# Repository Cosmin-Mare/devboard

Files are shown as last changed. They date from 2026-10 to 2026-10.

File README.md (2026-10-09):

# RP2040 Dev Board

A small, Pico-style development board built around the **RP2040**, designed in **KiCad 10**. USB-C, 3.3 V LDO, 2 MB QSPI flash, a BOOTSEL button, SWD header, and every GPIO broken out to two 20-pin 2.54 mm headers. Made to be ordered fully assembled from JLCPCB.

Screenshot 2026-10-06 at 7 39 09 PM
Screenshot 2026-10-06 at 7 42 24 PM

| | |
|---|---|
| MCU | Raspberry Pi RP2040 (QFN-56), 12 MHz crystal |
| Flash | Winbond W25Q16JV, 16 Mbit (2 MB) QSPI |
| Power | USB-C (5 V) → MCP1700-3.3 LDO (250 mA) |
| I/O | 26 GPIO (incl. 4 ADC), RUN, VBUS, 3V3, GND on headers; 3-pin SWD (1.27 mm) |
| Controls | BOOTSEL button (no reset button – RUN is on a header pin) |
| Board | 21 × 51 mm, 2-layer, 1.6 mm, headers 17.78 mm (700 mil) apart |
| Assembly | All SMD on the top side (JLCPCB), pin headers hand-soldered |

## Repository layout

```
hardware/kicad/        KiCad 10 project (schematic + PCB) – the source of truth
fabrication/gerbers/   Gerbers, drill files, .gbrjob exported from KiCad
fabrication/jlcpcb/    Ready-to-upload files: gerbers zip, bom.csv, cpl.csv
fabrication/extras/    IPC-D-356 netlist, ODB++, IPC-2581 XML, KiCad board report (.rpt)
bom/bom.csv            Full BOM with MPN + LCSC numbers
bom/BOM.md             Readable BOM
bom/jlcpcb-bom-match-*.xlsx   JLCPCB's BOM-tool match result (stock/prices at the time)
docs/ORDERING.md       Step-by-step JLCPCB order
docs/ASSEMBLY.md       What JLCPCB places vs. what you solder, plus hand-assembly notes
docs/BRINGUP.md       First power-up, flashing, and test checklist
docs/PINOUT.md         Header pinout
```

## Quick start

1. **Order** – follow [docs/ORDERING.md](docs/ORDERING.md). Upload `fabrication/jlcpcb/devboard-gerbers.zip`, then `bom.csv` and `cpl.csv`.
2. **Solder** the two 20-pin headers (and optionally the SWD header) – see [docs/ASSEMBLY.md](docs/ASSEMBLY.md).
3. **Bring up** – hold BOOTSEL, plug in USB-C, copy a `.uf2` onto the `RPI-RP2` drive. See [docs/BRINGUP.md](docs/BRINGUP.md).

## Editing the design

Open `hardware/kicad/devboard.kicad_pro` in KiCad 10. After changes, re-export Gerbers/drill (`File → Fabrication Outputs`), and the position file (`Fabrication Outputs → Component Placement`, CSV, SMD only, millimetres), then refresh `fabrication/` and `bom/`.

## Known notes / things to check before a re-order

- The schematic value for U3 reads `W25Q16JVZPIQ TR`, but JLCPCB matched `W25Q16JVUXIQ` (LCSC C2843335), which is the USON-8 3×2 mm variant matching the footprint. Consider correcting the schematic value so the BOM and part agree.
- JLCPCB's BOM tool flagged several passives as "comment does not match" (value text differs from the part description). The matches are the intended values; review once in the order preview.
- Always check part rotations in JLCPCB's 3D/placement preview (USB-C, RP2040 pin-1, regulator, crystal) before paying – CPL rotation conventions differ between KiCad and JLCPCB.
- No power LED, user LED or reset button are fitted.

## License

MIT. See [LICENSE](LICENSE).

---

Designed by [Cosmin Mare](https://mare-cosmin.ro/en/).

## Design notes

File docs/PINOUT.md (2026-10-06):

# Pinout

Two 20-pin 2.54 mm headers, 17.78 mm apart (same as a Raspberry Pi Pico). **Pin 1 is the end nearest the USB-C connector.** This is *not* the Pico pin order – pins are in the order below.

| Pin | J2 (left) | J3 (right) |
|---:|---|---|
| 1 | GPIO0 | VBUS (5 V from USB) |
| 2 | GPIO1 | GPIO29 / ADC3 |
| 3 | GND | GND |
| 4 | GPIO2 | GPIO28 / ADC2 |
| 5 | GPIO3 | +3V3 (regulator output) |
| 6 | GPIO4 | GPIO27 / ADC1 |
| 7 | GPIO5 | GPIO26 / ADC0 |
| 8 | GND | GND |
| 9 | GPIO6 | GPIO24 |
| 10 | GPIO7 | GPIO23 |
| 11 | GPIO8 | RUN (pull low to reset) |
| 12 | GPIO9 | GPIO22 |
| 13 | GND | GND |
| 14 | GPIO10 | GPIO21 |
| 15 | GPIO11 | GPIO20 |
| 16 | GPIO12 | GPIO19 |
| 17 | GPIO13 | GPIO18 |
| 18 | GND | GND |
| 19 | GPIO14 | GPIO17 |
| 20 | GPIO15 | GPIO16 |

**J4 – SWD (1.27 mm, 3-pin):** 1 = SWCLK, 2 = GND, 3 = SWDIO.

Notes
- GPIO29/ADC3 also senses VSYS on a Pico; here it is a free pin.
- GPIO24 and GPIO23 are exposed; GPIO25 (Pico's LED) is not.
- The 3V3 rail is from a 250 mA LDO shared with the RP2040 – budget accordingly.

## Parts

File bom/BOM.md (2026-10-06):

# Bill of Materials

Per board. 33 parts total (16 line items). Full data incl. manufacturer/MPN in [bom.csv](bom.csv).

| Designators | Qty | Value | Footprint | MPN | LCSC | Assembled by JLCPCB |
|---|--:|---|---|---|---|---|
| C1,C10 | 2 | 1uF | C_0402_1005Metric | CL05A105KA5NQNC | [C52923](https://www.lcsc.com/product-detail/C52923.html) | Yes |
| C2,C3,C4,C5,C6,C7,C8,C9,C11,C12,C17 | 11 | 0.1uF | C_0402_1005Metric | CL05B104KO5NNNC | [C1525](https://www.lcsc.com/product-detail/C1525.html) | Yes |
| C13,C14 | 2 | 10uF | C_0603_1608Metric | CL10A106KP8NNNC | [C19702](https://www.lcsc.com/product-detail/C19702.html) | Yes |
| C15,C16 | 2 | 33pF | C_0402_1005Metric | 0402CG330J500NT | [C1562](https://www.lcsc.com/product-detail/C1562.html) | Yes |
| J1 | 1 | USB_C_Receptacle_USB2.0_14P | USB_C_Receptacle_HRO_TYPE-C-31-M-12 | TYPE-C-31-M-12 | [C165948](https://www.lcsc.com/product-detail/C165948.html) | Yes |
| J2,J3 | 2 | Conn_01x20 | PinHeader_1x20_P2.54mm_Vertical | 2.54-1*20P直针 | [C50981](https://www.lcsc.com/product-detail/C50981.html) | No (hand-solder) |
| J4 | 1 | Conn_01x03 | PinHeader_1x03_P2.54mm_Vertical | 1.27-1*3P针 | [C24980](https://www.lcsc.com/product-detail/C24980.html) | No (hand-solder) |
| R1,R2 | 2 | 5.1k | R_0402_1005Metric | 0402WGF5101TCE | [C25905](https://www.lcsc.com/product-detail/C25905.html) | Yes |
| R3,R4 | 2 | 27 | R_0402_1005Metric | 0402WGF270JTCE | [C25100](https://www.lcsc.com/product-detail/C25100.html) | Yes |
| R5,R7 | 2 | 1k | R_0402_1005Metric | 0402WGF1001TCE | [C11702](https://www.lcsc.com/product-detail/C11702.html) | Yes |
| R6 | 1 | 10k | R_0402_1005Metric | 0402WGF1002TCE | [C25744](https://www.lcsc.com/product-detail/C25744.html) | Yes |
| SW1 | 1 | SW_Push | SW_Push_SPST_NO_Alps_SKRK | TS-1088-AR02016 | [C720477](https://www.lcsc.com/product-detail/C720477.html) | Yes |
| U1 | 1 | RP2040 | QFN-56-1EP_7x7mm_P0.4mm_EP3.2x3.2mm | RP2040 | [C2040](https://www.lcsc.com/product-detail/C2040.html) | Yes |
| U2 | 1 | MCP1700x-330xxTT | SOT-23 | MCP1700T-3302E/TT | [C39051](https://www.lcsc.com/product-detail/C39051.html) | Yes |
| U3 | 1 | W25Q16JVZPIQTR | Winbond_USON-8-1EP_3x2mm_P0.5mm_EP0.2x1.6mm | W25Q16JVUXIQ | [C2843335](https://www.lcsc.com/product-detail/C2843335.html) | Yes |
| Y1 | 1 | 12MHz | Crystal_SMD_3225-4Pin_3.2x2.5mm | X322512MSB4SI | [C9002](https://www.lcsc.com/product-detail/C9002.html) | Yes |

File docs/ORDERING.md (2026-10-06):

# Ordering from JLCPCB (PCB + assembly)

Files are in `fabrication/jlcpcb/`.

1. Go to <https://jlcpcb.com> → **Order now** → upload `devboard-gerbers.zip`.
2. Board settings that match the design:
   - Layers: **2**, Dimensions: **21.05 × 51.05 mm**
   - Thickness: **1.6 mm**, Surface finish: HASL (lead-free) or ENIG (your choice – the design has no special requirement)
   - Min track/space 0.2 mm, min drill 0.3 mm (standard capability)
3. Enable **PCB Assembly** → **Assemble top side only**. Pick quantity (the saved match was for 5 boards).
4. Upload `bom.csv` and `cpl.csv`. Make sure every row matches the LCSC number in the table below.
5. In the placement preview, check **pin-1 and rotation** of: U1 (RP2040), U2 (MCP1700 SOT-23), U3 (flash), Y1 (crystal), J1 (USB-C), SW1. Fix rotation in the preview if anything looks wrong.
6. J2, J3 (20-pin headers) and J4 (3-pin SWD header) showed **quantity 0** in the saved JLCPCB match – they are through-hole parts you solder yourself (see [ASSEMBLY.md](ASSEMBLY.md)).
7. Review the price and place the order.

## LCSC parts

| Ref | Value | LCSC | Type |
|---|---|---|---|
| C1, C10 | 1 µF 0402 | C52923 | Basic |
| C2–C9, C11, C12, C17 | 100 nF 0402 | C1525 | Basic |
| C13, C14 | 10 µF 0603 | C19702 | Basic |
| C15, C16 | 33 pF 0402 | C1562 | Basic |
| J1 | USB-C (HRO TYPE-C-31-M-12) | C165948 | Extended |
| R1, R2 | 5.1 kΩ 0402 | C25905 | Basic |
| R3, R4 | 27 Ω 0402 | C25100 | Extended |
| R5, R7 | 1 kΩ 0402 | C11702 | Basic |
| R6 | 10 kΩ 0402 | C25744 | Basic |
| SW1 | Tactile 4×3 mm (XUNPU TS-1088-AR02016) | C720477 | Basic |
| U1 | RP2040 | C2040 | Extended |
| U2 | MCP1700T-3302E/TT | C39051 | Extended |
| U3 | W25Q16JVUXIQ | C2843335 | Extended |
| Y1 | 12 MHz 3225 crystal (YXC X322512MSB4SI) | C9002 | Basic |
| J2, J3 *(hand-solder)* | 1×20 pin header 2.54 mm | C50981 | Extended |
| J4 *(hand-solder)* | 1×3 pin header 1.27 mm | C24980 | Extended |

The last saved JLCPCB estimate (2026-10-06, 5 assembled boards) was **~$17.27** for assembly parts; stock and prices change, so re-match before ordering. Extended parts add a per-part loading fee.

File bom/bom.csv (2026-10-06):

Designators | Qty | Value | Footprint | Manufacturer | MPN | LCSC | JLCPCB lib | Assembled by JLCPCB
C1,C10 | 2 | 1uF | C_0402_1005Metric | Samsung Electro-Mechanics | CL05A105KA5NQNC | C52923 | Basic | Yes
C2,C3,C4,C5,C6,C7,C8,C9,C11,C12,C17 | 11 | 0.1uF | C_0402_1005Metric | Samsung Electro-Mechanics | CL05B104KO5NNNC | C1525 | Basic | Yes
C13,C14 | 2 | 10uF | C_0603_1608Metric | Samsung Electro-Mechanics | CL10A106KP8NNNC | C19702 | Basic | Yes
C15,C16 | 2 | 33pF | C_0402_1005Metric | FH (Guangdong Fenghua Advanced Tech) | 0402CG330J500NT | C1562 | Basic | Yes
J1 | 1 | USB_C_Receptacle_USB2.0_14P | USB_C_Receptacle_HRO_TYPE-C-31-M-12 | Korean Hroparts Elec | TYPE-C-31-M-12 | C165948 | Extended | Yes
J2,J3 | 2 | Conn_01x20 | PinHeader_1x20_P2.54mm_Vertical | BOOMELE(Boom Precision Elec) | 2.54-1*20P直针 | C50981 | Extended | No (hand-solder)
J4 | 1 | Conn_01x03 | PinHeader_1x03_P2.54mm_Vertical | BOOMELE(Boom Precision Elec) | 1.27-1*3P针 | C24980 | Extended | No (hand-solder)
R1,R2 | 2 | 5.1k | R_0402_1005Metric | UNI-ROYAL(Uniroyal Elec) | 0402WGF5101TCE | C25905 | Basic | Yes
R3,R4 | 2 | 27 | R_0402_1005Metric | UNI-ROYAL(Uniroyal Elec) | 0402WGF270JTCE | C25100 | Extended | Yes
R5,R7 | 2 | 1k | R_0402_1005Metric | UNI-ROYAL(Uniroyal Elec) | 0402WGF1001TCE | C11702 | Basic | Yes
R6 | 1 | 10k | R_0402_1005Metric | UNI-ROYAL(Uniroyal Elec) | 0402WGF1002TCE | C25744 | Basic | Yes
SW1 | 1 | SW_Push | SW_Push_SPST_NO_Alps_SKRK | XUNPU | TS-1088-AR02016 | C720477 | Basic | Yes
U1 | 1 | RP2040 | QFN-56-1EP_7x7mm_P0.4mm_EP3.2x3.2mm | Raspberry Pi | RP2040 | C2040 | Extended | Yes
U2 | 1 | MCP1700x-330xxTT | SOT-23 | Microchip Tech | MCP1700T-3302E/TT | C39051 | Extended | Yes
U3 | 1 | W25Q16JVZPIQTR | Winbond_USON-8-1EP_3x2mm_P0.5mm_EP0.2x1.6mm | Winbond Elec | W25Q16JVUXIQ | C2843335 | Extended | Yes
Y1 | 1 | 12MHz | Crystal_SMD_3225-4Pin_3.2x2.5mm | YXC Crystal Oscillators | X322512MSB4SI | C9002 | Basic | Yes

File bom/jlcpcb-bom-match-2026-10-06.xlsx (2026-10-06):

JLCPCB BOM Tool - BOM Matching
BOM name：devboard-JLCPCB Assembly Order.xlsx |  |  | Download Time：2026-10-06 22:26:59 |  |  |  | * Our matching results are updated in real-time, but stock and prices may change. If it's been over 24 hours, please re-match before placing your order.
PCB Assembled Qty：5 |  |  | Est. Total Price：17.2668
Your BOM |  |  |  | Matched Parts |  |  |  |  |  |  | Order Information
Designator | Comment | Footprint | JLCPCB Part # | Matches | Part # | Manufacturer | Footprint | Description | Category | Warning | JLCPCB Part # | Product link | Lib Type | Qty | Source | Total Price ($)
C1,C10 | 1uF | C_0402_1005Metric |  | Select by Customer | CL05A105KA5NQNC | Samsung Electro-Mechanics | 0402 | 1uF 25V X5R ±10% 0402 Multilayer Ceramic Capacitors MLCC - SMD/SMT ROHS | Multilayer Ceramic Capacitors MLCC - SMD/SMT |  | C52923 | https://jlcpcb.com/partdetail/53938-CL05A105KA5NQNC/C52923 | Basic | 10 | 10 JLCPCB | 0.107
C2,C3,C4,C5,C6,C7,C8,C9,C11,C12,C17 | 0.1uF | C_0402_1005Metric |  | Select by Customer | CL05B104KO5NNNC | Samsung Electro-Mechanics | 0402 | 100nF 16V X7R ±10% 0402 Multilayer Ceramic Capacitors MLCC - SMD/SMT ROHS | Multilayer Ceramic Capacitors MLCC - SMD/SMT | 1.The comment (CL05B104KO5NNNC) of this part does not match the one (0.1uF) provided in your BOM. Please confirm; | C1525 | https://jlcpcb.com/partdetail/1877-CL05B104KO5NNNC/C1525 | Basic | 55 | 55 JLCPCB | 0.2475
C13,C14 | 10uF | C_0603_1608Metric |  | Select by System | CL10A106KP8NNNC | Samsung Electro-Mechanics | 0603 | 10V 10uF X5R ±10% 0603 Multilayer Ceramic Capacitors MLCC - SMD/SMT ROHS | Multilayer Ceramic Capacitors MLCC - SMD/SMT |  | C19702 | https://jlcpcb.com/partdetail/20411-CL10A106KP8NNNC/C19702 | Basic | 10 | 10 JLCPCB | 0.319
C15,C16 | 33pF | C_0402_1005Metric |  | Select by Customer | 0402CG330J500NT | FH (Guangdong Fenghua Advanced Tech) | 0402 | 33pF 50V C0G ±5% 0402 Multilayer Ceramic Capacitors MLCC - SMD/SMT ROHS | Multilayer Ceramic Capacitors MLCC - SMD/SMT |  | C1562 | https://jlcpcb.com/partdetail/1914-0402CG330J500NT/C1562 | Basic | 10 | 10 JLCPCB | 0.035
J1 | USB_C_Receptacle_USB2.0_14P | USB_C_Receptacle_HRO_TYPE-C-31-M-12 |  | Select by Customer | TYPE-C-31-M-12 | Korean Hroparts Elec | SMD | -30℃~+80℃ 1 10,000 cycles 16P 20V 5A 7.35mm Female Surface Mount, Right Angle Type-C SMD USB Connectors ROHS | USB Connectors |  | C165948 | https://jlcpcb.com/partdetail/Korean_HropartsElec-TYPE_C_31_M12/C165948 | Extended | 5 | 5 JLCPCB | 0.9285
J2,J3 | Conn_01x20 | PinHeader_1x20_P2.54mm_Vertical |  | Select by Customer | 2.54-1*20P直针 | BOOMELE(Boom Precision Elec) | 插件,P=2.54mm | -40℃~+105℃ 1 1x20P 2.54mm 20P 3A Black Brass Pin Header Through Hole 插件,P=2.54mm Pin Headers ROHS | Pin Headers |  | C50981 | https://jlcpcb.com/partdetail/51993-2_54_1_20P/C50981 | Extended | 0 | 0 JLCPCB | 0
J4 | Conn_01x03 | PinHeader_1x03_P2.54mm_Vertical |  | Select by Customer | 1.27-1*3P针 | BOOMELE(Boom Precision Elec) | 插件,P=1.27mm | -55℃~+105℃ 1 1.27mm 1.7mm 1x3P 2.5mm 3A 3P 3mm Black Brass Pin Header Through Hole 插件,P=1.27mm Pin Headers ROHS | Pin Headers |  | C24980 | https://jlcpcb.com/partdetail/25717-1_27_1_3P/C24980 | Extended | 0 | 0 JLCPCB | 0
R1,R2 | 5.1k | R_0402_1005Metric |  | Select by Customer | 0402WGF5101TCE | UNI-ROYAL(Uniroyal Elec) | 0402 | -55℃~+155℃ 5.1kΩ 50V 62.5mW Thick Film Resistor ±1% ±100ppm/℃ 0402 Chip Resistor - Surface Mount ROHS | Chip Resistor - Surface Mount | 1.The comment (0402WGF5101TCE) of this part does not match the one (5.1k) provided in your BOM. Please confirm; | C25905 | https://jlcpcb.com/partdetail/26648-0402WGF5101TCE/C25905 | Basic | 10 | 10 JLCPCB | 0.024
R3,R4 | 27 | R_0402_1005Metric |  | Select by Customer | 0402WGF270JTCE | UNI-ROYAL(Uniroyal Elec) | 0402 | -55℃~+155℃ 27Ω 50V 62.5mW Thick Film Resistor ±1% ±100ppm/℃ 0402 Chip Resistor - Surface Mount ROHS | Chip Resistor - Surface Mount | 1.The comment (0402WGF270JTCE) of this part does not match the one (27) provided in your BOM. Please confirm; | C25100 | https://jlcpcb.com/partdetail/25843-0402WGF270JTCE/C25100 | Extended | 22 | 22 JLCPCB | 0.0418
R5,R7 | 1k | R_0402_1005Metric |  | Select by Customer | 0402WGF1001TCE | UNI-ROYAL(Uniroyal Elec) | 0402 | -55℃~+155℃ 1kΩ 50V 62.5mW Thick Film Resistor ±1% ±100ppm/℃ 0402 Chip Resistor - Surface Mount ROHS | Chip Resistor - Surface Mount | 1.The comment (0402WGF1001TCE) of this part does not match the one (1k) provided in your BOM. Please confirm; | C11702 | https://jlcpcb.com/partdetail/12256-0402WGF1001TCE/C11702 | Basic | 10 | 10 JLCPCB | 0.018
R6 | 10k | R_0402_1005Metric |  | Select by Customer | 0402WGF1002TCE | UNI-ROYAL(Uniroyal Elec) | 0402 | -55℃~+155℃ 10kΩ 50V 62.5mW Thick Film Resistor ±1% ±100ppm/℃ 0402 Chip Resistor - Surface Mount ROHS | Chip Resistor - Surface Mount | 1.The comment (0402WGF1002TCE) of this part does not match the one (10k) provided in your BOM. Please confirm; | C25744 | https://jlcpcb.com/partdetail/26487-0402WGF1002TCE/C25744 | Basic | 5 | 5 JLCPCB | 0.017
SW1 | SW_Push | SW_Push_SPST_NO_Alps_SKRK |  | Select by Customer | TS-1088-AR02016 | XUNPU | SMD,4x3mm | -30℃~+80℃ 1.6N 100,000 cycles 12V 2mm 3.9mm 3mm 50mA Black Round Button SMD(SMT) Tab SPST Surface Mount,Vertical Without Bracket SMD,4x3mm Tactile Switches ROHS | Tactile Switches |  | C720477 | https://jlcpcb.com/partdetail/XUNPU-TS_1088AR02016/C720477 | Basic | 5 | 5 JLCPCB | 0.261
U1 | RP2040 | QFN-56-1EP_7x7mm_P0.4mm_EP3.2x3.2mm |  | Select by Customer | RP2040 | Raspberry Pi | LQFN-56(7x7) | 12bit 133MHz 30 LQFN-56(7x7) Microcontrollers (MCU/MPU/SOC) ROHS | Microcontrollers (MCU/MPU/SOC) |  | C2040 | https://jlcpcb.com/partdetail/RaspberryPi-RP2040/C2040 | Extended | 5 | 5 JLCPCB | 4.942
U2 | MCP1700x-330xxTT | SOT-23 |  | Select by Customer | MCP1700T-3302E/TT | Microchip Tech | SOT-23 | -40℃~+125℃@(Tj) 1 1.6uA 178mV@(250mA) 250mA 3.3V 44dB@(100Hz) 6V Fixed Over Temperature Protection、Short Circuit Protection Positive SOT-23 Voltage Regulators - Linear, Low Drop Out (LDO) Regulators ROHS | Voltage Regulators - Linear, Low Drop Out (LDO) Regulators |  | C39051 | https://jlcpcb.com/partdetail/MicrochipTech-MCP1700T_3302ETT/C39051 | Extended | 5 | 5 JLCPCB | 1.9755
U3 | W25Q16JVZPIQTR | Winbond_USON-8-1EP_3x2mm_P0.5mm_EP0.2x1.6mm |  | Select by Customer | W25Q16JVUXIQ | Winbond Elec | USON-8-EP(2x3) | -40℃~+85℃ 100,000 cycles 10uA 133MHz 16Mbit 2.7V~3.6V 20 Years 3ms SPI USON-8-EP(2x3) NOR FLASH ROHS | NOR FLASH |  | C2843335 | https://jlcpcb.com/partdetail/WinbondElec-W25Q16JVUXIQ/C2843335 | Extended | 5 | 5 JLCPCB | 7.8765
Y1 | 12MHz | Crystal_SMD_3225-4Pin_3.2x2.5mm |  | Select by Customer | X322512MSB4SI | YXC Crystal Oscillators | SMD3225-4P | -40℃~+85℃ 12MHz 20pF 80Ω Crystal Oscillator ±10ppm ±20ppm SMD3225-4P Crystals ROHS | Crystals |  | C9002 | https://jlcpcb.com/partdetail/YXC_CrystalOscillators-X322512MSB4SI/C9002 | Basic | 5 | 5 JLCPCB | 0.474

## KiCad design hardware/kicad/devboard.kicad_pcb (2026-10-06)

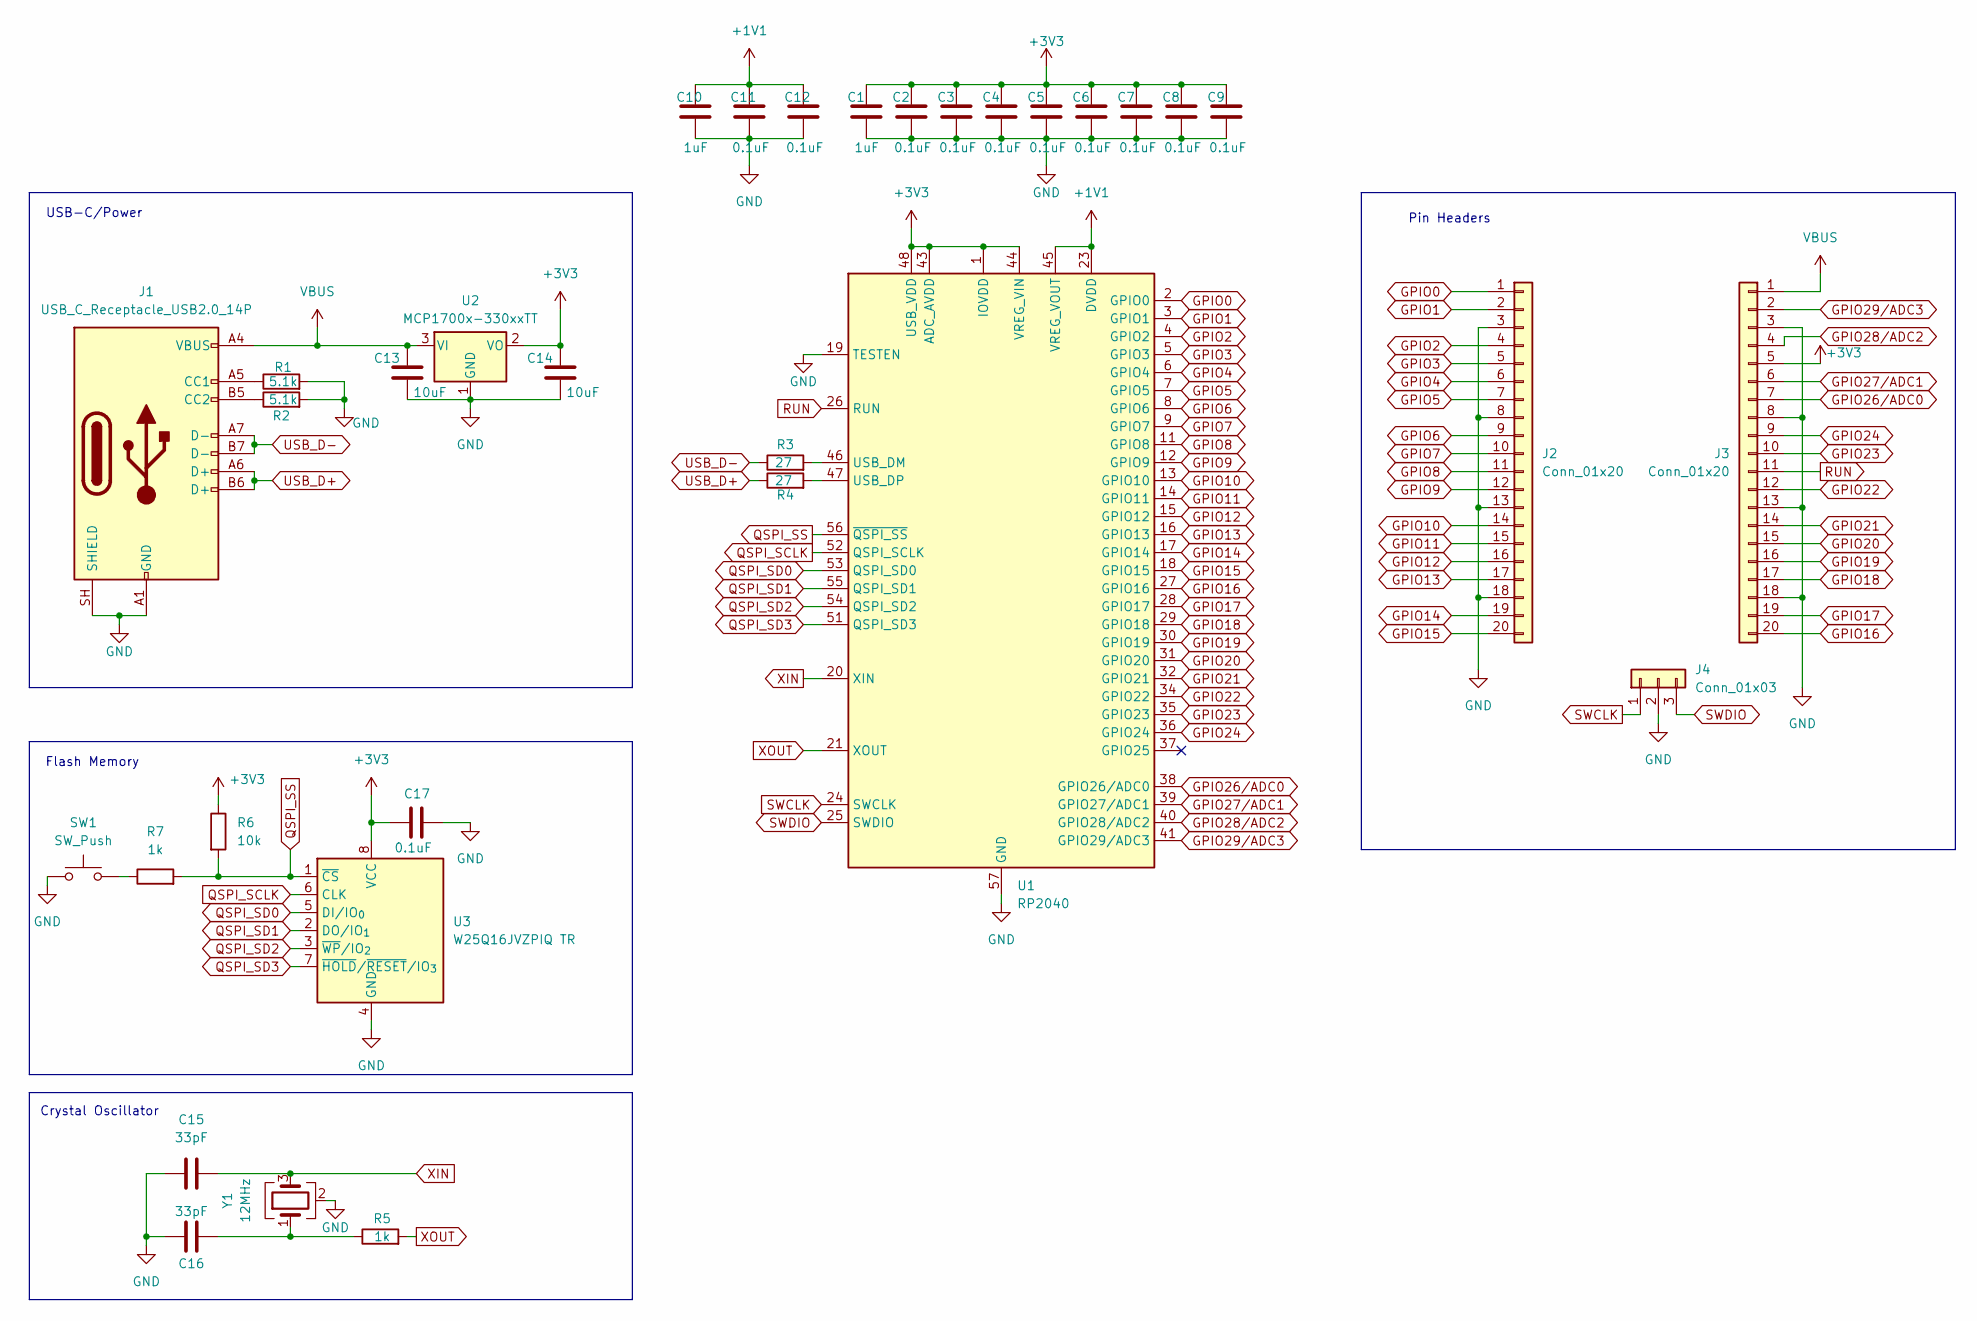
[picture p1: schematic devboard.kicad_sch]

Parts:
C1, C10: 1uF; C_0402_1005Metric
C2, C3, C4, C5, C6, C7, C8, C9, C11, C12, C17: 0.1uF; C_0402_1005Metric
C13, C14: 10uF; C_0603_1608Metric
C15, C16: 33pF; C_0402_1005Metric
J1: USB_C_Receptacle_USB2.0_14P; USB_C_Receptacle_HRO_TYPE-C-31-M-12
J2, J3: Conn_01x20; PinHeader_1x20_P2.54mm_Vertical
J4: Conn_01x03; PinHeader_1x03_P2.54mm_Vertical
R1, R2: 5.1k; R_0402_1005Metric
R3, R4: 27; R_0402_1005Metric
R5, R7: 1k; R_0402_1005Metric
R6: 10k; R_0402_1005Metric
SW1: SW_Push; SW_Push_SPST_NO_Alps_SKRK
U1: RP2040; QFN-56-1EP_7x7mm_P0.4mm_EP3.2x3.2mm
U2: MCP1700x-330xxTT; SOT-23
U3: W25Q16JVZPIQ TR; Winbond_USON-8-1EP_3x2mm_P0.5mm_EP0.2x1.6mm
Y1: 12MHz; Crystal_SMD_3225-4Pin_3.2x2.5mm

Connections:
+1V1: C10.1, C11.1, C12.1, U1.23 (DVDD), U1.45 (VREG_VOUT), U1.50 (DVDD)
+3V3: C1.1, C2.1, C3.1, C4.1, C5.1, C6.1, C7.1, C8.1, C9.1, C14.1, C17.1, J3.5, R6.1, U1.1 (IOVDD), U1.10 (IOVDD), U1.22 (IOVDD), U1.33 (IOVDD), U1.42 (IOVDD), U1.43 (ADC_AVDD), U1.44 (VREG_VIN), U1.48 (USB_VDD), U1.49 (IOVDD), U2.2 (VO), U3.8 (VCC)
GND: C1.2, C2.2, C3.2, C4.2, C5.2, C6.2, C7.2, C8.2, C9.2, C10.2, C11.2, C12.2, C13.2, C14.2, C15.1, C16.1, C17.2, J1.A1 (GND), J1.A12 (GND), J1.B1 (GND), J1.B12 (GND), J1.SH (SHIELD), J2.3, J2.8, J2.13, J2.18, J3.3, J3.8, J3.13, J3.18, J4.2, R1.2, R2.2, SW1.1, U1.19 (TESTEN), U1.57 (GND), U2.1 (GND), U3.4 (GND), Y1.2 (G), Y1.4 (G)
GPIO0: J2.1, U1.2 (GPIO0)
GPIO1: J2.2, U1.3 (GPIO1)
GPIO2: J2.4, U1.4 (GPIO2)
GPIO3: J2.5, U1.5 (GPIO3)
GPIO4: J2.6, U1.6 (GPIO4)
GPIO5: J2.7, U1.7 (GPIO5)
GPIO6: J2.9, U1.8 (GPIO6)
GPIO7: J2.10, U1.9 (GPIO7)
GPIO8: J2.11, U1.11 (GPIO8)
GPIO9: J2.12, U1.12 (GPIO9)
GPIO10: J2.14, U1.13 (GPIO10)
GPIO11: J2.15, U1.14 (GPIO11)
GPIO12: J2.16, U1.15 (GPIO12)
GPIO13: J2.17, U1.16 (GPIO13)
GPIO14: J2.19, U1.17 (GPIO14)
GPIO15: J2.20, U1.18 (GPIO15)
GPIO16: J3.20, U1.27 (GPIO16)
GPIO17: J3.19, U1.28 (GPIO17)
GPIO18: J3.17, U1.29 (GPIO18)
GPIO19: J3.16, U1.30 (GPIO19)
GPIO20: J3.15, U1.31 (GPIO20)
GPIO21: J3.14, U1.32 (GPIO21)
GPIO22: J3.12, U1.34 (GPIO22)
GPIO23: J3.10, U1.35 (GPIO23)
GPIO24: J3.9, U1.36 (GPIO24)
GPIO26/ADC0: J3.7, U1.38 (GPIO26/ADC0)
GPIO27/ADC1: J3.6, U1.39 (GPIO27/ADC1)
GPIO28/ADC2: J3.4, U1.40 (GPIO28/ADC2)
GPIO29/ADC3: J3.2, U1.41 (GPIO29/ADC3)
unnamed: C16.2, R5.1, Y1.1
unnamed: J1.A5 (CC1), R1.1
unnamed: J1.B5 (CC2), R2.1
unnamed: R7.1, SW1.2
unnamed: R3.2, U1.46 (USB_DM)
unnamed: R4.2, U1.47 (USB_DP)
QSPI_SCLK: U1.52 (QSPI_SCLK), U3.6 (CLK)
QSPI_SD0: U1.53 (QSPI_SD0), U3.5 (DI/IO_{0})
QSPI_SD1: U1.55 (QSPI_SD1), U3.2 (DO/IO_{1})
QSPI_SD2: U1.54 (QSPI_SD2), U3.3 (~WP/IO_{2})
QSPI_SD3: U1.51 (QSPI_SD3), U3.7 (~HOLD/~RESET/IO_{3})
QSPI_SS: R6.2, R7.2, U1.56 (~QSPI_SS), U3.1 (~CS)
RUN: J3.11, U1.26 (RUN)
SWCLK: J4.1, U1.24 (SWCLK)
SWDIO: J4.3, U1.25 (SWDIO)
USB_D+: J1.A6 (D+), J1.B6 (D+), R4.1
USB_D-: J1.A7 (D-), J1.B7 (D-), R3.1
VBUS: C13.1, J1.A4 (VBUS), J1.A9 (VBUS), J1.B4 (VBUS), J1.B9 (VBUS), J3.1, U2.3 (VI)
XIN: C15.2, U1.20 (XIN), Y1.3
XOUT: R5.2, U1.21 (XOUT)

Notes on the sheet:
USB-C/Power
Crystal Oscillator
Pin Headers
Flash Memory

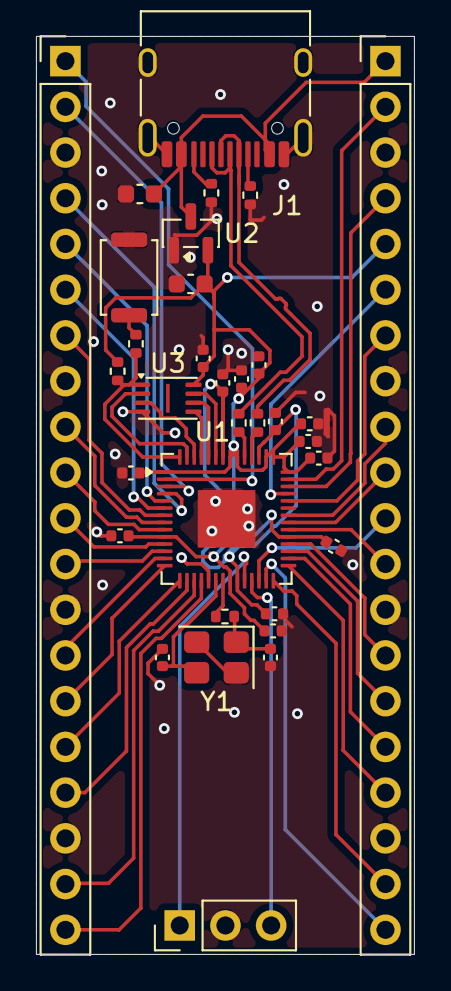
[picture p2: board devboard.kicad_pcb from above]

Board: 2 copper layers, 21.0 x 51.0 mm, 33 parts (0 on the bottom side), 52 nets.

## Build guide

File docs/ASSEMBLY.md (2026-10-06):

# Assembly

## What JLCPCB places (top side)
All SMD parts: U1 RP2040, U2 LDO, U3 flash, Y1 crystal, J1 USB-C, SW1 BOOTSEL button, and all resistors/capacitors (R1–R7, C1–C17).

## What you solder
| Part | Notes |
|---|---|
| J2, J3 – 1×20 header, 2.54 mm | Solder from the **bottom** if you want pins down (breadboard use) or top for pins up. Use a breadboard or a second header to hold them straight and parallel; the rows are 17.78 mm apart. |
| J4 – 1×3 header, 1.27 mm | Optional. Only needed for SWD debugging. |

Tools: soldering iron (~330 °C), leaded or lead-free solder, flux, a breadboard to align headers.

### Steps
1. Inspect the board under magnification: USB-C shell pins, RP2040 QFN pins (no bridges), flash chip.
2. Press the 20-pin headers into a breadboard (long pins down), place the PCB on top, solder one pin per header, check they're square, then solder the rest.
3. Optionally solder J4.
4. Clean flux (isopropyl alcohol + brush).
5. Continue with [BRINGUP.md](BRINGUP.md).

## Circuit summary (for debugging)
- **USB:** J1 D+/D− → 27 Ω series resistors (R4/R3) → RP2040 USB pins. CC1/CC2 each pulled to GND with 5.1 kΩ (R1/R2) so a USB-C host supplies 5 V.
- **Power:** VBUS → C13 10 µF → MCP1700-3.3 (U2) → +3V3 with C14 10 µF. 11 × 100 nF + 2 × 1 µF decoupling around U1.
- **Clock:** 12 MHz crystal Y1 with 33 pF load caps (C15, C16); R5 1 kΩ in series on XOUT.
- **Flash:** U3 on QSPI (SS, SCLK, SD0–SD3).
- **BOOTSEL:** SW1 pulls QSPI_SS to GND through R7 (1 kΩ); R6 10 kΩ pulls QSPI_SS to 3V3.
- **RUN:** brought out on J3 pin 11, no reset button.

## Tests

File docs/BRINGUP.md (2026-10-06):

# Bring-up checklist

Before first power-up (no USB):
- [ ] Multimeter continuity: **+3V3 ↔ GND** and **VBUS ↔ GND** are *not* shorted (expect high resistance / charging cap).
- [ ] Visual check of RP2040 and USB-C solder joints.

First power-up:
- [ ] Plug USB-C into a PC. VBUS (J3 pin 1) ≈ 5 V; +3V3 (J3 pin 5) ≈ 3.3 V.
- [ ] If the 3V3 rail is wrong or the regulator is hot, unplug and re-inspect U2 orientation, C13/C14 and U1 power pins.

Flash firmware:
- [ ] Hold **BOOTSEL (SW1)**, plug in USB-C, release. A drive named **RPI-RP2** should appear.
- [ ] Drag a `.uf2` onto it (e.g. MicroPython or Pico SDK `blink`). Note: there is **no onboard LED**; blink a GPIO with an external LED + resistor (e.g. GPIO15 on J2 pin 20).
- [ ] If no drive appears: check the 12 MHz crystal, the flash (U3) solder joints, USB D+/D− (27 Ω resistors) and CC resistors.

Optional SWD:
- [ ] J4 pins: SWCLK, GND, SWDIO. Use a Raspberry Pi Debug Probe or picoprobe.

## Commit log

2026-10-06 Initial commit: RP2040 dev board (KiCad project, fabrication outputs, BOM, docs)
    Claude-Session: https://claude.ai/code/session_014QUZJu8MRhJpzdY1Lnz7Uu
    [bom.csv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]
2026-10-06 Update README with image and board specifications
    Added image and specifications for the RP2040 Dev Board.
